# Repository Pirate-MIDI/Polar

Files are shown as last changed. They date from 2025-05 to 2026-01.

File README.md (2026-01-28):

# Polar Pico, Mini, Plus, and Max
This repo contains hardware design files for ESP32-S3 platforms for Greg Smith's firmware which enables MIDI control of the ToneX One from IK Multimedia.
Greg's original project can be found [here](https://github.com/builty/tonexonecontroller)

PIRATE MIDI now manufactures and sells these [Polar controllers](https://www.piratemidi.com/products/polar), and 10% of all sales go to Greg Smith to support his awesome work. Many thanks to Greg for his encouragement and support in making these controllers available.

## Polar Pico
Polar Pico is a screenless MIDI translator for ToneX One and ToneX
- 9V DC Centre Negative 2.1mm Barrel Jack
- 3.5mm TRS (Type A) MIDI Input Jack
- USB Type-C USB Host Jack

Polar Pico powers the ToneX One - no other power needed.
Simply connect your ToneX One or ToneX to the USB port, connect power to the 9V jack, and you can send wired or wireless MIDI.

[Buy a Polar Pico Here](https://piratemidi.com/products/polar?variant=46533908693044)



## Polar Mini
Polar Mini has a 1.69" LCD screen and is a MIDI translator for ToneX One and ToneX
- 9V DC Centre Negative 2.1mm Barrel Jack
- 3.5mm TRS (Type A) MIDI Input Jack
- USB Type-C USB Host Jack

Polar Mini powers the ToneX One - no other power needed.
Simply connect your ToneX One or ToneX to the USB port, connect power to the 9V jack, and you can send wired or wireless MIDI and see your presets and wireless status on the screen.

[Buy a Polar Mini Here](https://piratemidi.com/products/polar?variant=46533908725812)



## Polar Plus
Polar Plus has a 1.69" LCD screen, two built-in footswitches, and is a MIDI translator for ToneX One and ToneX
- 9V DC Centre Negative 2.1mm barrel Jack
- 3.5mm TRS (Type A) MIDI Input Jack
- USB Type-C USB Host Jack
- Two High Quality Momentary Footswitches

Polar Plus powers the ToneX One - no other power needed.
Simply connect your ToneX One or ToneX to the USB port, connect power to the 9V jack, and you can send wired or wireless MIDI and see your presets and wireless status on the screen. The built-in footswitches can be assigned in the web configurator, but scroll through presets by default. 

[Buy a Polar Plus Here](https://piratemidi.com/products/polar?variant=46533908758580)



## Polar Max
Polar Max has a 4.3" Touchscreen LCD, two built-in footswitches, and is a MIDI translator for ToneX One and ToneX with onboard UI for editing presets and parameter. 
- 9V DC Centre Negative 2.1mm Barrel Jack
- 3.5mm TRS (Type A) MIDI Input Jack
- 3.5mm TRS (Type A) MIDI Output Jack (not yet implemented in firmware)
- USB Type-C USB Host Jack
- Two High Quality Momentary Footswitches

Polar Max powers the ToneX One - no other power needed.
Simply connect your ToneX One or ToneX to the USB port, connect power to the 9V jack, and you can send wired or wireless MIDI and see or edit your presets and wireless status on the touchscreen. The built-in footswitches can be assigned in the web configurator, but scroll through presets by default. 

[Buy a Polar Max Here](https://piratemidi.com/products/polar?variant=46900052197428)

Polar Max Context 2 1350px

## New to MIDI?
If MIDI confuses or intimidates you, fear not! We've been helping people get started with MIDI for years, and last year we collated our expertise into two great resources for beginners and power-users alike. **Tones & Technology** is an eBook written specifically to guitarists and pedalboard users to help you understand and get more out of MIDI. The [Foundational Chapter](https://www.tonesandtechnology.com/product/tones-technology-free-chapter) is permanently free to download as a great MIDI primer you can share with your friends, and the [Full eBook](https://www.tonesandtechnology.com/product/tones-tech-pdf) has 135 pages with 75+ custom diagrams and images to help you learn more advanced MIDI control techniques. 

## About Us
PIRATE MIDI is an Australian manufacturer of MIDI controllers, hubs, and more. We love MIDI and we love innovative solutions that help you think less and create more. We ship worldwide from Australia, and we have a workmanship guarantee and a 1 year warranty that we support worldwide.

We've been making MIDI controllers and other devices since 2020. If you'd like to learn more about us, check out our appearance on [The Gear Podcast](https://www.youtube.com/watch?v=aMcJVGF4TDE&t=1s&pp=ygUcdGhlIGdlYXIgcG9kY2FzdCBwaXJhdGUgbWlkaQ%3D%3D) or [Chairmen of the Boards Podcast](https://www.youtube.com/watch?v=8-HLmsmi4O0&t=13s&pp=ygUiY2hhaXJtZW4gb2YgdGhlIGJvYXJkcyBwaXJhdGUgbWlkaQ%3D%3D)

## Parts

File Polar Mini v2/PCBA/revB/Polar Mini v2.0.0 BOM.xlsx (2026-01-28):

Qty | Value | Footprint | Designator | JLC_PREF | PART_NO
2 |  | SOD-323 | D2, D3 | C191023 | SOD323-SCHOTTKY-1A
4 | 100K | 0402-RES | R5, R7, R15, R33 | C25741 | R0402-100K
3 | 100n | 0402_CAP | C8, C12, C14 | C307331 | C0402-100NF-50V-X7R
1 | 10K | 0402-RES | R16 | C25744 | R0402-10K
1 | 10R | 0603-RES | R8 | C22859 | R0603-10R
3 | 10u | 0603_CAP | C5, C7, C1 | C96446 | C0603-10U-25V-X5R
1 | 12V | SOD-323 | D6 | C19077447 | ZENER-SOD-323-12V
1 | 1u | 0402_CAP | C6 | C52923 | C0402-1U-25V-X5R
1 | 220R | 0402-RES | R1 | C25091 | R0402-220R
1 | 22R | 0402-RES | R2 | C25092 | R0402-22R
2 | 22u | 0805_CAP | C4, C11 | C45783 | C0805-22U-25V-X5R
1 | 27K | 0402-RES | R4 | C25771 | R0402-27K
1 | 2K2 | 0402-RES | R9 | C25879 | R0402-2K2
1 | 2u2 | L1008 | L6 | C237482 | L1008-2U2H-2A5
1 | 33R | 0402-RES | R3 | C25105 | R0402-33R
1 | 47u | 1206_CAP | C13 | C96123 | C1206-47U-10V-X5R
4 | 5K1 | 0402-RES | R6, R12, R13, R14 | C25905 | R0402-5K1
1 | DC3.6MM | CUI_PJ-072C-SMT-TR | J1 | C3094066 | PJ-072C-SMT-TR
1 | DISP_LCD_GENERIC_SPI_1.69_WRAPUNDER | TFT_1.69IN_240X280_12P | DISP1 | C9900239771
1 | ESP32-S3-WROOM-1 | XCVR_ESP32-S3-WROOM-1-N16R2 | U3 | C2913205 | ESP32-S3-WROOM-1-N16R2
3 | FIDUCIALROUND_1MM | FIDUCIAL_ROUND_1MM | FD1, FD2, FD3 |  | FIDUCIAL
1 | H11L1S | SMD6 | OK1 | C78589 | H11L1S
2 | LED0603_R | CHIPLED_0603 | D4, D5 | C2286 | LED-0603-RED
2 | MOMENTARYHOR_2.5MM_3MM | SW_B3U-3000P | S3, S4 | C778147
1 | N-channel | SOT23 | Q1 | C8545 | NFET-LOW-SIG-SWITCH-SOT-23-3
2 | SCREW-FASTENER2.5 | M2.5-PANHEAD-VIA | MP1, MP2
1 | SI2309CDS | SOT23 | Q6 | C10493 | SI2309
14 | TEST_PADSB1,27 | B1,27 | TP1, TP2, TP3, TP4, TP5, TP7, TP8, TP9, TP10, TP11, TP12, TP13, TP14, TP15
1 | TLV76733DRV | SON65P200X200X80-7N | U5 | C2848334 | TLV76733DRVR
1 | TPS629206DRLR | SOT-583 | U8 | C5219292 | TPS629206DRLR
2 | TRS-TIP-RING-SW | PJ-342B | J2, J3 | C7507452 | PJ-342 141
1 | USBC_2.0 | 12402012E212A | J4 | C2988369 | USBC-2.0-TOP

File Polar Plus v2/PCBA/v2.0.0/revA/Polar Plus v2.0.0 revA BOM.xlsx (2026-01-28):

Qty | Value | Footprint | Designator | JLC_PREF | PART_NO
1 |  | DO-214AC | D3 | C151924
1 |  | SOD-123 | D5 | C82544
1 |  | SOD-323 | D1 | C191023 | SOD323-SCHOTTKY-1A
6 | 100K | 0402-RES | R7, R13, R15, R27, R33, R49 | C25741 | R0402-100K
10 | 100n | 0402_CAP | C4, C6, C7, C9, C13, C14, C16, C26, C29, C60 | C307331 | C0402-100NF-50V-X7R
1 | 10K | 0402-RES | R50 | C25744 | R0402-10K
1 | 10R | 0603-RES | R8 | C22859 | R0603-10R
3 | 10u | 0603_CAP | C5, C12, C15 | C96446 | C0603-10U-25V-X5R
1 | 12V | SOD-323 | D6 | C19077447 | ZENER-SOD-323-12V
4 | 1K | 0402-RES | R5, R21 | C11702 | R0402-1K
2 | 1u | 0402_CAP | C1, C2 | C52923 | C0402-1U-25V-X5R
1 | 200K | 0402-RES | R6 | C25764 | R0402-200K
2 | 220R | 0402-RES | R1, R16, R9, R19 | C25091 | R0402-220R
3 | 22K | 0402-RES | R11, R14, R23 | C25768 | R0402-22K
1 | 22R | 0402-RES | R2 | C25092 | R0402-22R
1 | 22u | 0603_CAP | C10 | C59461 | C0603-22UF-6V3-X5R
1 | 22u | 0805_CAP | C3 | C45783 | C0805-22U-25V-X5R
1 | 27K | 0402-RES | R10 | C25771 | R0402-27K
2 | 2K2 | 0402-RES | R43, R44 | C25879 | R0402-2K2
2 | 2u2 | L1008 | L1, L2 | C237482 | L1008-2U2H-2A5
2 | 33K | 0402-RES | R12, R24 | C25779 | R0402-33K
1 | 33R | 0402-RES | R3 | C25105 | R0402-33R
4 | 47u | 1206_CAP | C8, C11, C27, C28 | C96123 | C1206-47U-10V-X5R
5 | 5K1 | 0402-RES | R4, R17, R29, R31, R32 | C25905 | R0402-5K1
1 | 741G32 | SOT23-5 | U5 | C7470
2 | ARGBSK6812-MINI-E | SK6812MINI-E | LED1, LED2 | C5149201 | SK6812MINI-E
2 | COMP_SINGLE_5PIN | SOT23-5 | U1, U3 | C5310980
1 | DCPCB_MOUNT_TH_SLOT | DCJACK_2MM_PTH_SLOT | J4 |  | DC-2.1-TH-SLOT
1 | DISP_LCD_GENERIC_SPI_1.69_WRAPUNDER | TFT_1.69IN_240X280_12P | DISP1 | C9900239771
1 | ESP32-S3-WROOM-1 | XCVR_ESP32-S3-WROOM-1-N16R2 | U8 | C2913205 | ESP32-S3-WROOM-1-N16R2
3 | FIDUCIALROUND_1MM | FIDUCIAL_ROUND_1MM | FD1, FD2, FD3 |  | FIDUCIAL
1 | H11L1S | SMD6 | OK1 | C78589 | H11L1S
2 | LED0603_R | CHIPLED_0603 | D9, D10 | C2286 | LED-0603-RED
2 | LEDIR12-21C/TR8 | IR12-21C/TR8 | D2, D4 | C181893 | IR26-61C/L302/TR8
2 | MOMENTARYHOR_2.5MM_3MM | SW_B3U-3000P | S1, S2 | C778147
1 | N-channel | SOT23 | Q1 | C8545 | NFET-LOW-SIG-SWITCH-SOT-23-3
2 | N_PHOTO | PT12-21B-TR8 | Q2, Q4 | C264383
2 | SCREW-FASTENER3 | M3-PANHEAD-VIA | MP1, MP2
1 | SI2309CDS | SOT23 | Q6 | C10493 | SI2309
2 | TEST_PADSB1,27 | B1,27 | TP14, TP15
2 | TPS56124 | SOT-563 | U2, U4 | C42040978 | TPS561243DRLR
2 | TRS-TIP-RING-SW | PJ-342B | J5, J6 | C7507452 | PJ-342 141
1 | USBC_2.0 | 12402012E212A | J3 | C2988369 | USBC-2.0-TOP

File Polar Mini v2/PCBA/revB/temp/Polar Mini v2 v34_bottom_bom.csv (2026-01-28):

Comment | Designator | Footprint | LCSC Part #
1u | D2 D3 C6 | 0402_CAP
2K2 | R9 | 0402-RES
2u2 | L6 | L1008
5K1 | R6 R12 R13 R14 | 0402-RES
10K | R16 | 0402-RES
10R | R8 | 0603-RES
10V | D6 | SOD-323
10u | C1 C5 C7 | 0603_CAP
22R | R2 | 0402-RES
22u | C4 C11 | 0805_CAP
27K | R4 | 0402-RES
33R | R3 | 0402-RES
47u | C13 | 1206_CAP
100K | R5 R7 R15 R33 | 0402-RES
100n | C8 C12 C14 | 0402_CAP
220R | R1 | 0402-RES
DC3.6MM | J1 | CUI_PJ-072C-SMT-TR
ESP32-S3-WROOM-1 | U3 | XCVR_ESP32-S3-WROOM-1-N16R2
FIDUCIALROUND_1MM | FD1 FD2 FD3 | FIDUCIAL_ROUND_1MM
H11L1S | OK1 | SMD6
LED0603_R | D4 D5 | CHIPLED_0603
MOMENTARYHOR_2.5MM_3MM | S3 S4 | SW_B3U-3000P
N-channel | Q1 | SOT23
SI2309CDS | Q6 | SOT23
TEST_PADSB1 27 | TP1 | B1 27
TEST_PADSB1 27 | TP2 | B1 27
TEST_PADSB1 27 | TP3 | B1 27
TEST_PADSB1 27 | TP4 | B1 27
TEST_PADSB1 27 | TP5 | B1 27
TEST_PADSB1 27 | TP7 | B1 27
TEST_PADSB1 27 | TP8 | B1 27
TEST_PADSB1 27 | TP9 | B1 27
TEST_PADSB1 27 | TP10 | B1 27
TEST_PADSB1 27 | TP11 | B1 27
TEST_PADSB1 27 | TP12 | B1 27
TEST_PADSB1 27 | TP13 | B1 27
TEST_PADSB1 27 | TP14 | B1 27
TEST_PADSB1 27 | TP15 | B1 27
TLV76733DRV | U5 | SON65P200X200X80-7N
TPS629206DRLR | U8 | SOT-583
TRS-TIP-RING-SW | J2 J3 | PJ-342B
USBC_2.0 | J4 | 12402012E212A

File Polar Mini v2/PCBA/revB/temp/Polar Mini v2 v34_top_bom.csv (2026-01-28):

Comment | Designator | Footprint | LCSC Part #
DISP_LCD_GENERIC_SPI_1.69_WRAPUNDER | DISP1 | TFT_1.69IN_240X280_12P

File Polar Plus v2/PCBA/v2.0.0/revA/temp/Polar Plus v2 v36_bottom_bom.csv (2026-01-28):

Comment | Designator | Footprint | LCSC Part #
1K | D1 D3 D5 R5 R9 R19 R21 | 0402-RES
1u | C1 C2 | 0402_CAP
2K2 | R43 R44 | 0402-RES
2u2 | L1 L2 | L1008
5K1 | R4 R17 R29 R31 R32 | 0402-RES
10K | R50 | 0402-RES
10R | R8 | 0603-RES
10u | C5 C12 C15 | 0603_CAP
12V | D6 | SOD-323
22K | R11 R14 R23 | 0402-RES
22R | R2 | 0402-RES
22u | C3 | 0805_CAP
22u | C10 | 0603_CAP
27K | R10 | 0402-RES
33K | R12 R24 | 0402-RES
33R | R3 | 0402-RES
47u | C8 C11 C27 C28 | 1206_CAP
100K | R7 R13 R15 R27 R33 R49 | 0402-RES
100n | C4 C6 C7 C9 C13 C14 C16 C26 C29 C60 | 0402_CAP
200K | R6 | 0402-RES
220R | R1 R16 | 0402-RES
741G32 | U5 | SOT23-5
ARGBSK6812-MINI-E | LED1 LED2 | SK6812MINI-E
COMP_SINGLE_5PIN | U1 U3 | SOT23-5
ESP32-S3-WROOM-1 | U8 | XCVR_ESP32-S3-WROOM-1-N16R2
FIDUCIALROUND_1MM | FD1 FD2 FD3 | FIDUCIAL_ROUND_1MM
H11L1S | OK1 | SMD6
LED0603_R | D9 D10 | CHIPLED_0603
LEDIR12-21C/TR8 | D2 D4 | IR12-21C/TR8
MOMENTARYHOR_2.5MM_3MM | S1 S2 | SW_B3U-3000P
N-channel | Q1 | SOT23
N_PHOTO | Q2 Q4 | PT12-21B-TR8
SI2309CDS | Q6 | SOT23
TEST_PADSB1 27 | TP14 | B1 27
TEST_PADSB1 27 | TP15 | B1 27
TPS56124 | U2 U4 | SOT-563
TRS-TIP-RING-SW | J5 J6 | PJ-342B
USBC_2.0 | J3 | 12402012E212A

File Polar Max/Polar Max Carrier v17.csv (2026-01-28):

Comment | Designator | Footprint | JLCPCB Part # | Quantity | MPN
1 | D7 | SOD-323 |  | 1 | 1N4148WX-TP | 1N4148
2 | J7 | 1X3_PADS |  | 1 |  | 1X3PADS
3 | IC1 | SO14 |  | 1 | 74HC14-SOIC-14 | 7414D
4 | D8, D9, D10 | DO-214AC |  | 3 |  | BIDIRECTIONAL
5 | J1 | DCJACK_2MM_PTH_SLOT |  | 1 | DC-2.1-TH-SLOT | DCPCB_MOUNT_TH_SLOT
6 | D4 | SOD-323 |  | 1 | SOD323-SCHOTTKY-1A | DIODE-SCHOTTKYGEN_SOD-323
7 | D1 | SOD-323 |  | 1 | ZENER-SOD-323-12V | DIODE-ZENER12V
8 | FD1, FD2, FD3 | FIDUCIAL_ROUND_1MM |  | 3 | FIDUCIAL | FIDUCIALROUND_1MM
9 | F1, F2 | 0603-FUSE |  | 2 | PTC-0603-6V-1.5A | FUSE1PPTC_0603_6V_1.5A
10 | OK1 | SMD6 |  | 1 | H11L1S | H11L1S
11 | J3, J4 | JST_S2B-PH-SM4-TB |  | 2 | S2B-PH-SM4-TB(LF)(SN) | JST_PH_2
12 | J2 | JST_SM12B-SRSS-TB |  | 1 |  | JST_SH_12
13 | D3 | CHIPLED_0603 |  | 1 | LED-0603-GREEN | LED0603_G
14 | D2, D5, D6 | CHIPLED_0603 |  | 3 | LED-0603-RED | LED0603_R
15 | U2 | SO08 |  | 1 |  | RS485SOIC
16 | MP1, MP2, MP3, MP4 | M3-PANHEAD-VIA |  | 4 |  | SCREW-FASTENER3
17 | Q1 | SOT23 |  | 1 | SI2309 | SI2309CDS
18 | C3, C4, C5, C6, C7 | 0603_CAP |  | 5 | C0603-100NF-50V-X7R | SMD-MLCCC0603-100N-50V-X7R
19 | C1 | 0805_CAP |  | 1 | C0805-10UF-25V-X7R | SMD-MLCCC0805-10U-25V-X7R
20 | R4, R11 | 0603-RES |  | 2 | R0603-1K | STDR0603-1K
21 | R9 | 0603-RES |  | 1 | R0603-20R | STDR0603-20R
22 | R5, R6, R7 | 0603-RES |  | 3 | R0603-220R | STDR0603-220R
23 | R1 | 0603-RES |  | 1 | R0603-2K2 | STDR0603-2K2
24 | R8 | 0603-RES |  | 1 | R0603-33R | STDR0603-33R
25 | R2 | 0603-RES |  | 1 | R0603-39K | STDR0603-39K
26 | R13 | 0603-RES |  | 1 | RC0603FR-0756KL | STDR0603-56K
27 | R3, R10, R14, R15, R16 | 0603-RES |  | 5 | R0603-5K1 | STDR0603-5K1
28 | J5, J6 | CUI_SJ1-3525N |  | 2 | SJ1-3525N | TRS

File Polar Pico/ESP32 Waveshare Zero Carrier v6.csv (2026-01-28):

Comment | Designator | Footprint | JLCPCB Part # | Quantity | MPN
1 | L1 | L1008 |  | 1 | L1008-2U2H-2A5 | 2-PIN-INDUCTORL1008-2U2-2A5
2 | J2 | DCJACK_2MM_PTH_SLOT |  | 1 | DC-2.1-TH-SLOT | DCPCB_MOUNT_TH_SLOT
3 | D1, D2 | SOD-323 |  | 2 | SOD323-SCHOTTKY-1A | DIODE-SCHOTTKYGEN_SOD-323
4 | FD1, FD2, FD3 | FIDUCIAL_ROUND_1MM |  | 3 | FIDUCIAL | FIDUCIALROUND_1MM
5 | OK1 | SMD6 |  | 1 | H11L1S | H11L1S
6 | D3 | CHIPLED_0603 |  | 1 | LED-0603-GREEN | LED0603_G
7 | MP1, MP2, MP3, MP4 | M3-PANHEAD-VIA |  | 4 |  | SCREW-FASTENER3
8 | C1 | 0805_CAP |  | 1 | C0805-10UF-25V-X7R | SMD-MLCCC0805-10U-25V-X7R
9 | C2 | 1210_CAP |  | 1 | C1210-22U-25V | SMD-MLCCC1210-22U-25V-X7R
10 | R4 | 0603-RES |  | 1 | R0603-100K | STDR0603-100K
11 | R5 | 0603-RES |  | 1 | R0603-1K | STDR0603-1K
12 | R1 | 0603-RES |  | 1 | R0603-220R | STDR0603-220R
13 | R3 | 0603-RES |  | 1 | R0603-27K | STDR0603-27K
14 | R2 | 0603-RES |  | 1 | R0603-5K1 | STDR0603-5K1
15 | U1 | SOT-5X3 |  | 1 | TPS629206DRLR | TPS629206DRLR
16 | J1 | CUI_SJ1-3525N |  | 1 | SJ1-3525N | TRS
17 | U2 | WAVESHARE_ESP32_ZERO |  | 1 |  | WAVESHARE_ESP32_ZERO

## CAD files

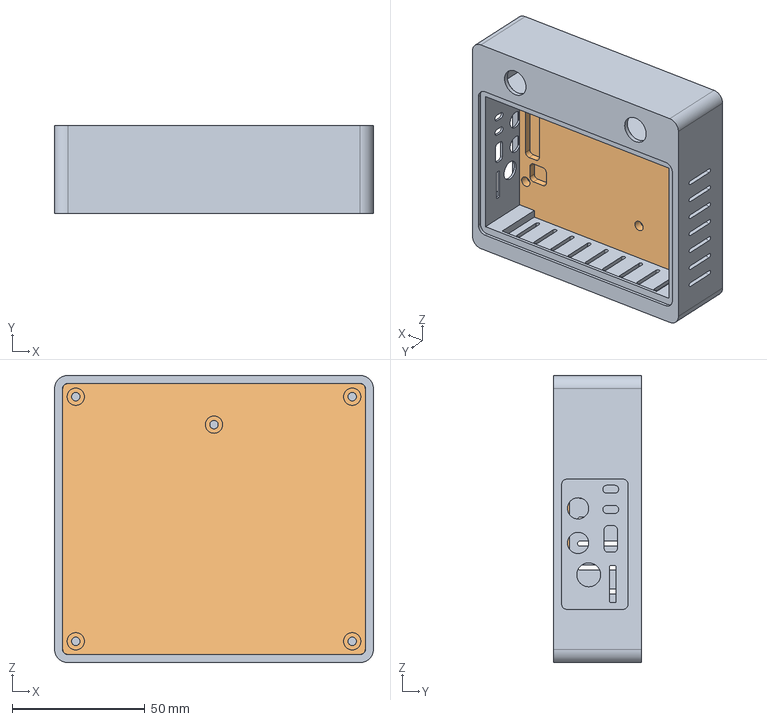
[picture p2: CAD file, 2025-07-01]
Polar Max/Polar Max Enclosure v105.step
120.0 x 33.0 x 108.0 mm
Top
Middle

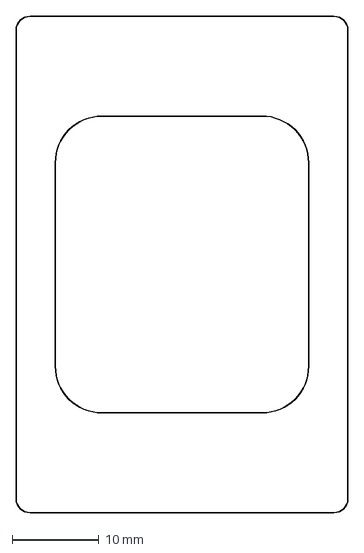
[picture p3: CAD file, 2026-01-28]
Polar Mini v2/Enclosure/Polar Mini v2 Overlay Sketch.dxf
38.2 x 57.2 mm

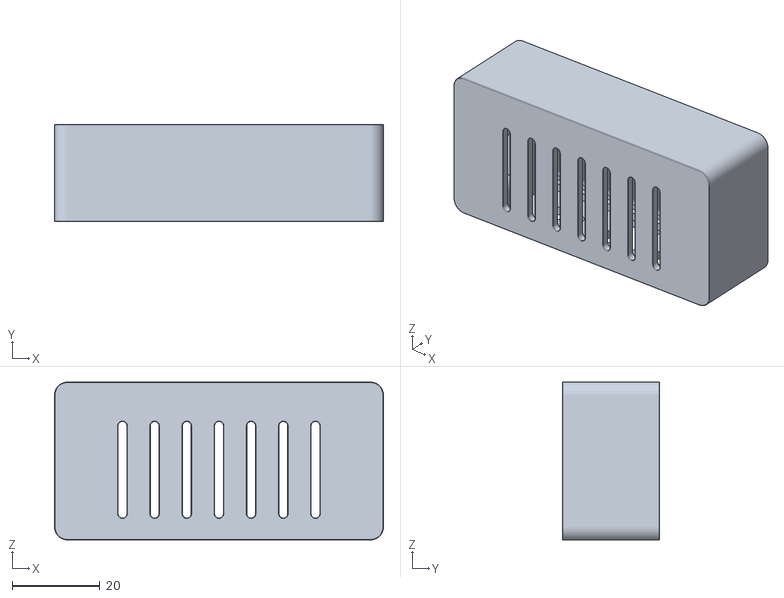
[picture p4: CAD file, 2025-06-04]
Polar Pico/Polar Pico Enclosure v43.stl
75.0 x 22.2 x 36.0

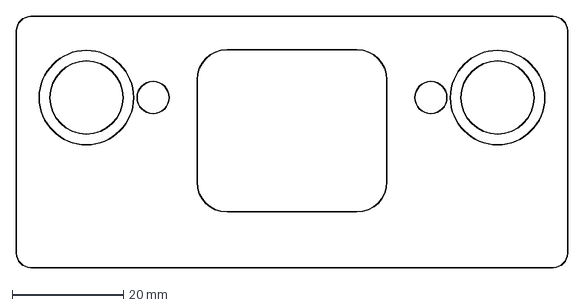
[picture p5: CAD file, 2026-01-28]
Polar Plus v2/Enclosure/Polar Plus v2 Overlay Sketch.dxf
99.2 x 45.2 mm

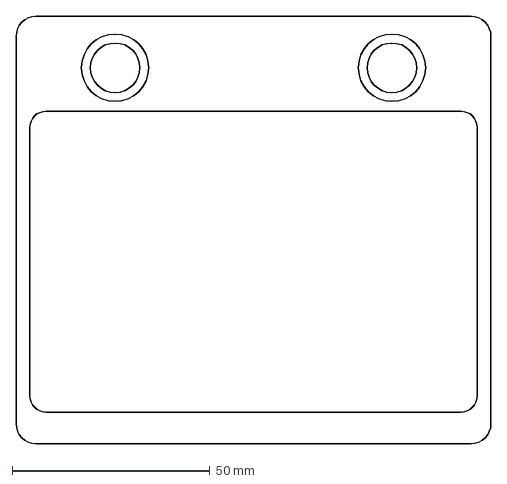
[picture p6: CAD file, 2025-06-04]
Polar Max/Polar Max Overlay.dxf
120.0 x 108.0 mm

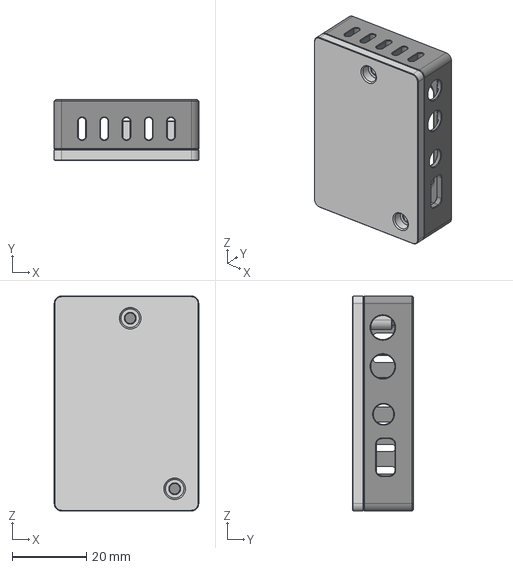
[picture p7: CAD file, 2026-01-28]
Polar Mini v2/Enclosure/Polar Mini v2 Enclosure v35.step
39.0 x 16.5 x 58.0 mm
Bottom
Top

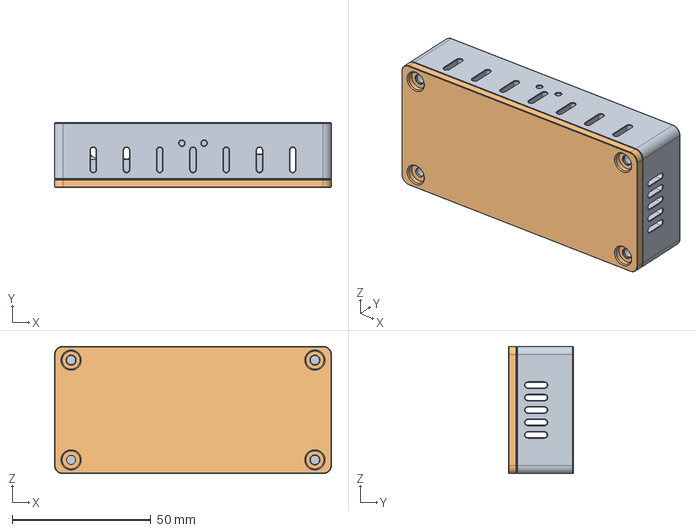
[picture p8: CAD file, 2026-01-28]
Polar Plus v2/Enclosure/Polar Plus v2 Enclosure v44.step
100.0 x 23.5 x 46.0 mm
Top
Bottom

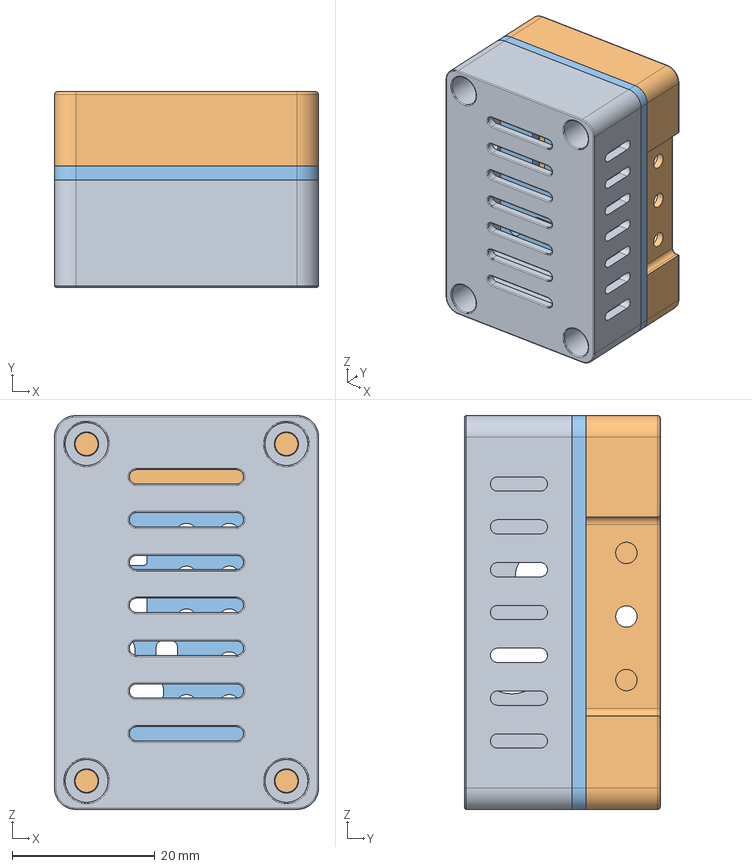
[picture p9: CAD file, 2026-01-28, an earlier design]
Polar Mini/Polar Mini Enclosure v84.step
37.0 x 27.4 x 55.2 mm
Bottom
Top
Middle

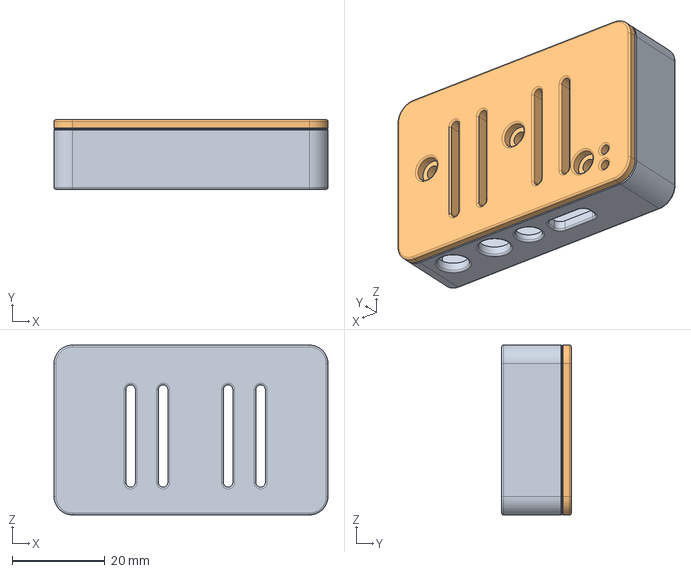
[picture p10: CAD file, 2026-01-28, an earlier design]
Polar Pico v2/Enclosure/Polar Pico Enclosure v40.step
59.0 x 15.0 x 36.6 mm

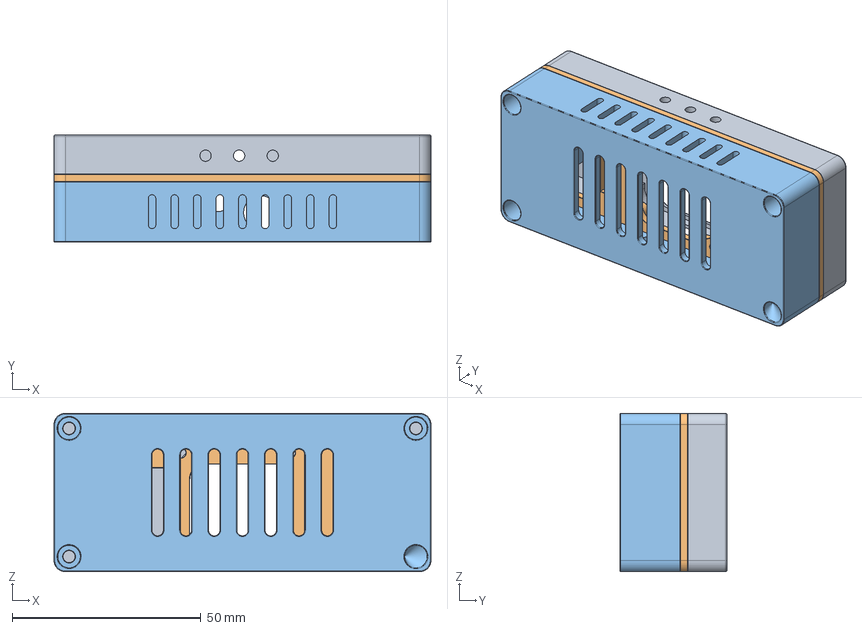
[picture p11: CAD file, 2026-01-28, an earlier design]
Polar Plus/Polar Plus Enclosure v49.step
100.0 x 28.4 x 42.0 mm
Top
Middle
Bottom

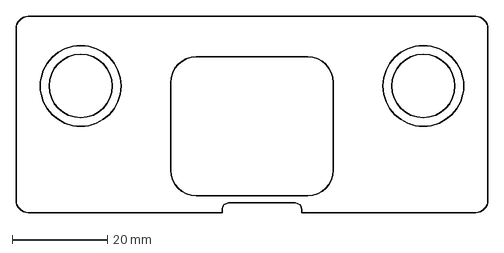
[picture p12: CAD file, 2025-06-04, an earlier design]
Polar Plus/Polar Plus Overlay.dxf
99.2 x 41.2 mm

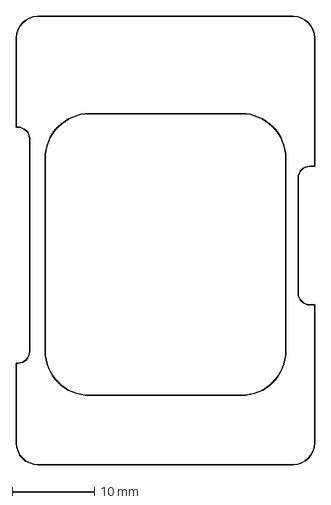
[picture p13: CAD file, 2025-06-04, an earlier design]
Polar Mini/Polar Mini Overlay DXF.dxf
36.2 x 54.4 mm

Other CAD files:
Polar Mini v2/Enclosure/Polar Mini v2 Enclosure v37.step
Polar Mini v2/Enclosure/Polar Mini v2 Enclosure v38.step
Polar Mini/Polar Mini Enclosure v85.stl
Polar Plus/Polar Plus Enclosure v49.stl

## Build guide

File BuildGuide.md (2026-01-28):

# Polar Controller DIY Build Guide

> ⚠️ This guide is for DIY builders and tinkerers. Pirate MIDI sells fully assembled units, but as part of our open-source commitment, we’re making this construction guide available for personal and non-commercial builds.

**[1. Hardware Assembly](https://github.com/Builty/TonexOneController/blob/main/WebConfiguration.md#entering-web-control)**

**[2. Installing Firmware](https://github.com/Builty/TonexOneController/blob/main/WebConfiguration.md#entering-web-control)**

**[3. Testing & Power-Up](https://github.com/Builty/TonexOneController/blob/main/WebConfiguration.md#entering-web-control)**

---

## 🧰 What You'll Need

Each variant of the Polar controller shares common elements. Below are general tools and materials you'll need.

### 🛠 Tools

- Soldering iron + solder
- Screwdriver set
- Heat-set insert tool or soldering iron with insert tip
- Flush cutters (for preparing wires)
- 3D printer (for enclosure) or printed parts
- Acrylic glue or double-sided tape (for protective overlay)
- JST crimping tool (if not using pre-crimped JST leads)

---

## 🔗 Polar Resources

- 📐 3D Enclosure Models: [Polar Pico](https://github.com/Pirate-MIDI/Polar/tree/main/Polar%20Pico), [Polar Mini](https://github.com/Pirate-MIDI/Polar/tree/main/Polar%20Mini), [Polar Plus](https://github.com/Pirate-MIDI/Polar/tree/main/Polar%20Plus), [Polar Max](https://github.com/Pirate-MIDI/Polar/tree/main/Polar%20Max)
- ⚡ Schematic & PCB Layout: [Polar Pico](https://github.com/Pirate-MIDI/Polar/tree/main/Polar%20Pico), [Polar Mini](https://github.com/Pirate-MIDI/Polar/tree/main/Polar%20Mini), [Polar Plus](https://github.com/Pirate-MIDI/Polar/tree/main/Polar%20Plus), [Polar Max](https://github.com/Pirate-MIDI/Polar/tree/main/Polar%20Max)
- 📄 [Firmware Source Code](https://github.com/Builty/TonexOneController)
- 📦 [Buy Pre-Assembled Units](https://piratemidi.com/)
- 📦 [Buy Waveshare ESP32 Boards](https://waveshare.com)

---

## 🔩 General Components List For All Variants

| Component | Description |
|---|--- |
| Custom PCB | Input & power designed for each variant |
| Waveshare Board | ESP32-S3 Variants (main brain) |
| 3D Printed Enclosure | STL provided; print in PLA or PETG (preferred)  |
| Heat-Set Inserts | Brass M3 |
| M3 & M2 Screws | Machine Thread (not tapping) |
| JST Connector | For PCB to Waveshare connection |
| Acrylic Overlay (optional)| Laser-cut, protective top panel |

---

# 🔧 Hardware Assembly Instructions

Each variant has its own steps below. If you're unsure which variant you're building, check the product comparison table on [our website](https://piratemidi.com/products/polar).

---

## Polar Pico (No Screen)

Minimalist version – ideal for under-board use.

**[📺 Polar Pico Assembly Video Guide COMING SOON!]()**

### Parts List

- 1x Polar Pico PCB
- [1x Waveshare ESP32-S3 Zero](https://www.waveshare.com/esp32-s3-zero.htm)
- 1x 3D printed enclosure 
- [4x M3x4mmx5mm Heat-set Inserts](https://github.com/user-attachments/assets/3e2e96b9-6922-4ddc-a0e5-bb1fc9a778b4)
- 4x M3x7mm screws
- [1x JST-SH 12-pin Dual-Male Cable](https://github.com/user-attachments/assets/c0d687e7-e608-4e23-b043-ad0c6be05575)
- Optional: Acrylic Protective Overlay

### Steps

1. **Solder Waveshare headers to PCB**
   Step 1: Soldering headers

2. **Heat-insert brass M3 inserts into 3D printed enclosure**
   Step 3: Heat set inserts

3. **Mount PCB and Waveshare into enclosure and secure with screws**

4. *(Optional)* Apply acrylic overlay using adhesive or standoffs.

---

## Polar Mini (Screen, No Switches)

Screen-only version for visual feedback in tight spaces.

**[📺 Polar Mini Assembly Video Guide COMING SOON!]()**

### Parts List

- 1x Polar Mini PCB  
- [1x Waveshare ESP32-S3 1.69](https://www.waveshare.com/esp32-s3-lcd-1.69.htm)
- 1x 3D printed enclosure
- [4x M3x4mmx5mm Heat-set Inserts](https://github.com/user-attachments/assets/3e2e96b9-6922-4ddc-a0e5-bb1fc9a778b4)
- 4x M3x7mm screws
- [1x JST-SH 12-pin Dual-Male Cable](https://github.com/user-attachments/assets/c0d687e7-e608-4e23-b043-ad0c6be05575)
- Optional: Acrylic Protective Overlay

### Steps

(Same general steps as Pico, with attention to screen alignment)

1. **Connect PCB to Waveshare 1.69 module with JST cable**
   Step: Screen and MCU soldering

2. **Heat-insert brass M3 inserts into 3D printed enclosure**

3. **Mount PCB and Screen into enclosures with care to align screen**

4. **Close enlclosure with screws**

5.  *(Optional)* Apply acrylic overlay using adhesive or standoffs.

---

## Polar Plus (Screen + 2 Footswitches)

**[📺 Polar Plus Assembly Video Guide COMING SOON!]()**

This version includes two footswitches for changing presets or other toggles.

### Additional Parts

- 2x Momentary, Normally Open (NO) footswitches   
- Wiring for switches

### Steps

1. **Solder wires to footswitches**
2. **Insert footswitches in enclosure and fasten**
3. **Solder footswitch wires onto PCB**
4. **Attach screen and MCU as per Mini**
5. **Secure all components into enclosure**
   Footswitch mounting
6. *(Optional)* Apply acrylic overlay

---

## Polar Max (Touchscreen + Full Control)

The flagship controller with touchscreen and full ToneX One editing onboard.

**[📺 Polar Max Assembly Video Guide](https://youtu.be/EYmiK8_B6EI)**

### Additional Parts

- [1x Waveshare 4.3b Touchscreen Module](https://www.waveshare.com/esp32-s3-touch-lcd-4.3b.htm) 
- 2x Momenatry Normally-Open (NO) Footswitches
- 1x JST-SH 12-pin connector with ferrules or open wires on other end

### Steps

1. **Install heat-set inserts**
2. **Solder wires to footswitches**
3. **Install footswitches into enclosure**
4. **Secure display into 3D printed housing**
5. **Fasten PCB to bottom plate of enclosure**
6. **Connect PCB and Waveshare with JST to Ferrules wire harness - See circuit diagram for details**
7. **Connect footswitches to PCB**
8. **Close enclosure and fasten with screws**
9. *(Optional)* Install overlay or protective cover

---

# 🖥️ Installing Firmware

To install the firmware, follow the instructions [found on the original project page here](https://github.com/Builty/TonexOneController/blob/main/FirmwareUploading.md).

---

# 🧪 Testing & Power-Up

1. Power via USB or 9V 2.1mm center-negative barrel jack  
2. Connect to [Web Configurator](https://github.com/Builty/TonexOneController/blob/main/WebConfiguration.md#entering-web-control) 
3. Test MIDI input and screen functionality.
   
   > ⚠️ Wired MIDI needs to be activated in the web configurator
4. Confirm footswitch response. (if applicable)

---

## 🧼 Tips & Troubleshooting

- If the 9v Power or MIDI input doesn't work, double-check the JST pinout or your manual wiring if you didn't use JST.
- Waveshare boards may not have factory firmware. Flash firmware before deciding your unit is "dead".
- Over-tightening screws can crack the enclosure. Don’t overdo it.
- If you have a construction issue, you can contact us in our [Discord Server](https://discord.gg/x722K7ksA6) (Polar Channel), or on the original open source project discussion tab. 

---

## 📸 Contributing

Found an error in these instructions? Feel free to submit a pull request!

---

## 📜 License

This project is licensed under the MIT License. Commercial resale of DIY units is not permitted under our license.

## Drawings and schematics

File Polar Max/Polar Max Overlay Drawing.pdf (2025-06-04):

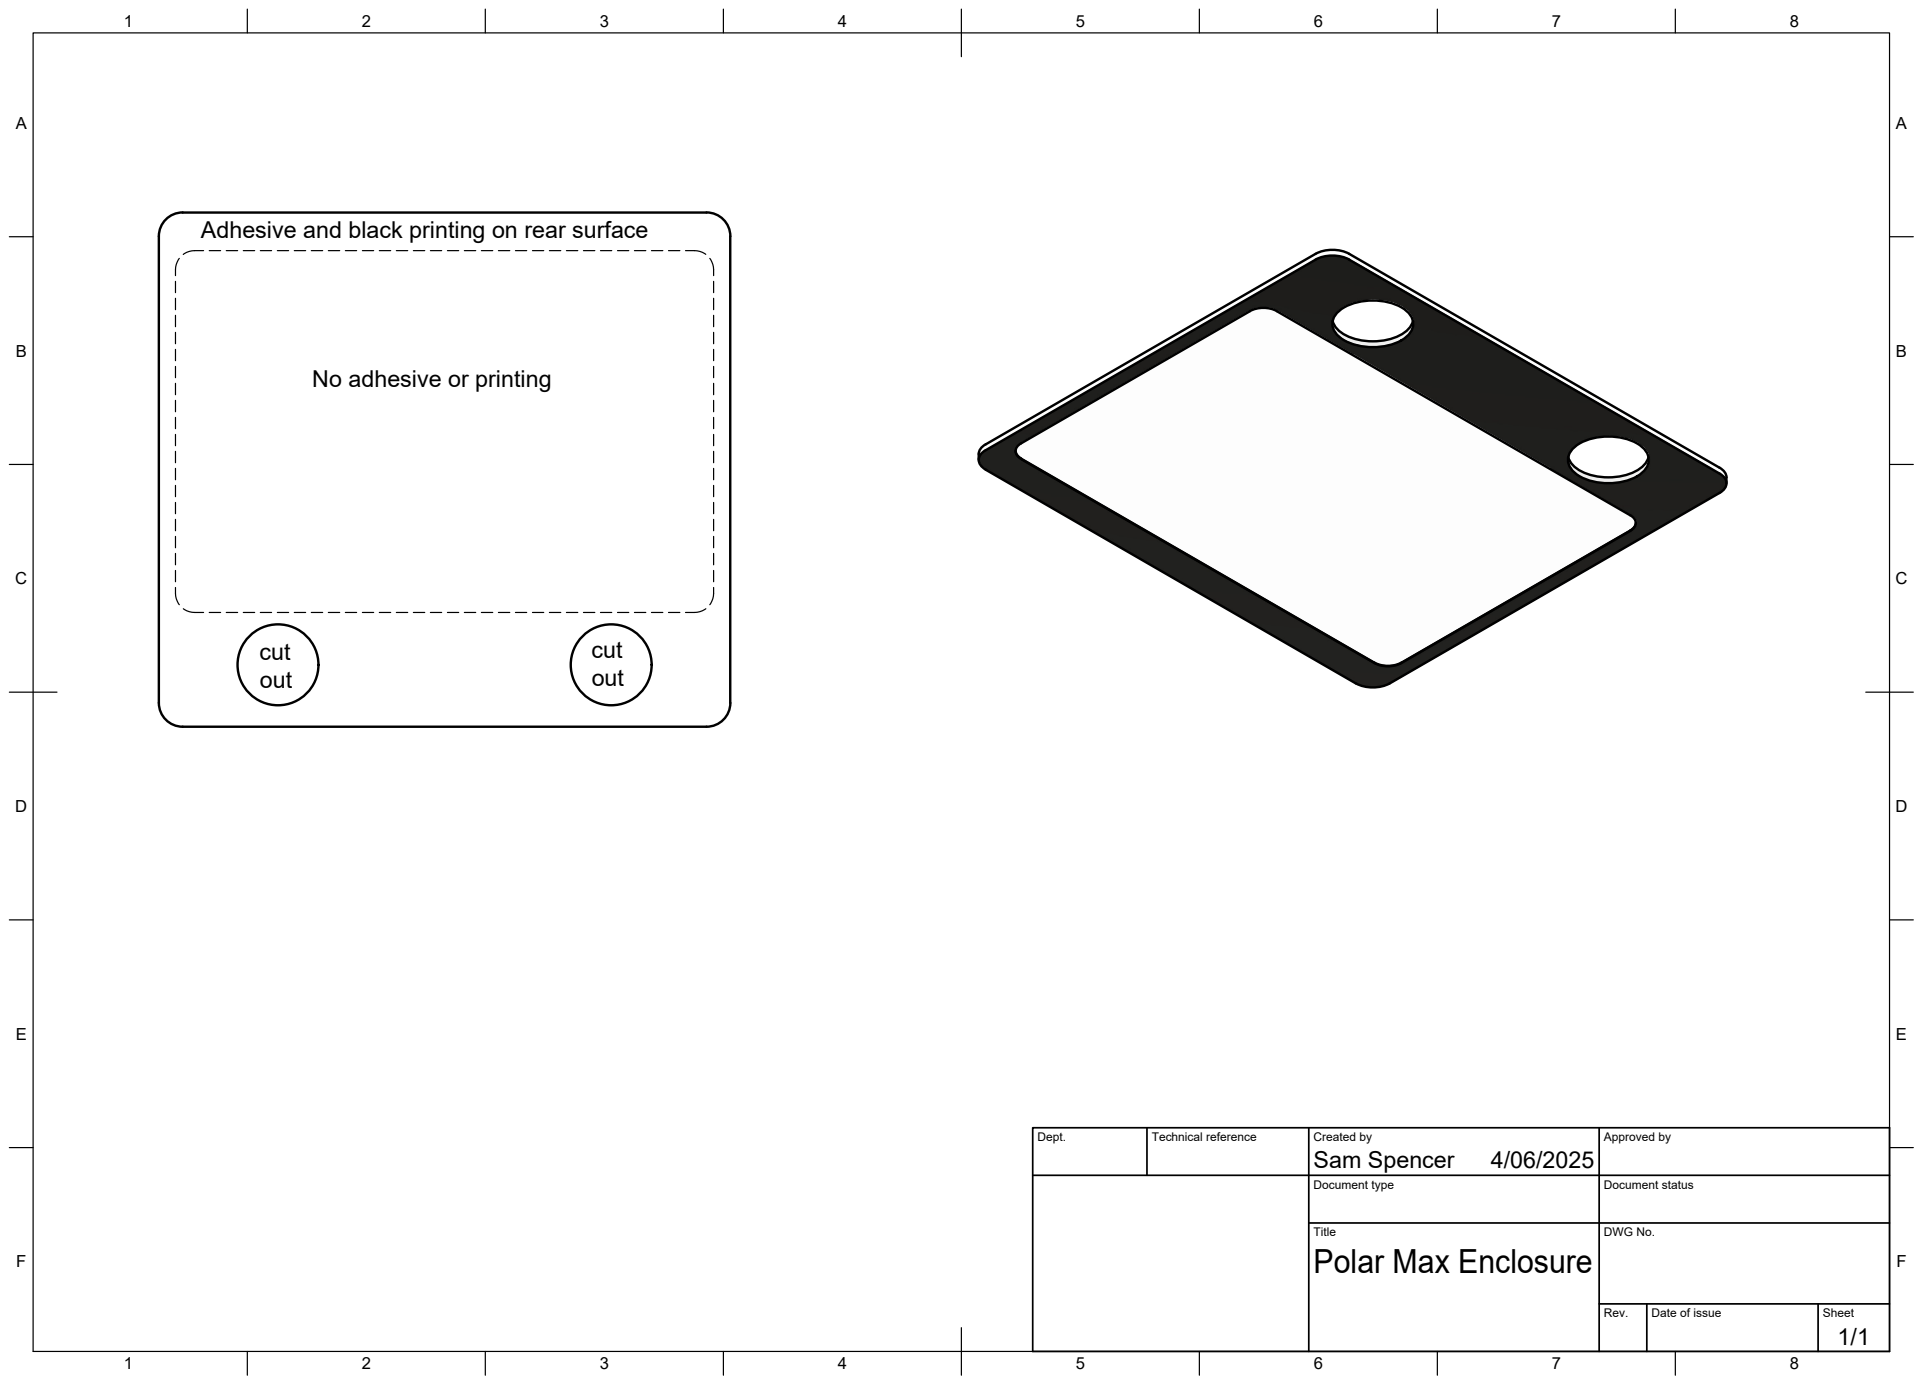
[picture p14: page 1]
Title; DWG No.; Rev.; Date of issue; Sheet

Adhesive and black printing on rear surface

No adhesive or printing

Dept. | Technical reference | Created by Sam Spencer 4/06/2025 | Approved by

Document type | Document status

Polar Max Enclosure

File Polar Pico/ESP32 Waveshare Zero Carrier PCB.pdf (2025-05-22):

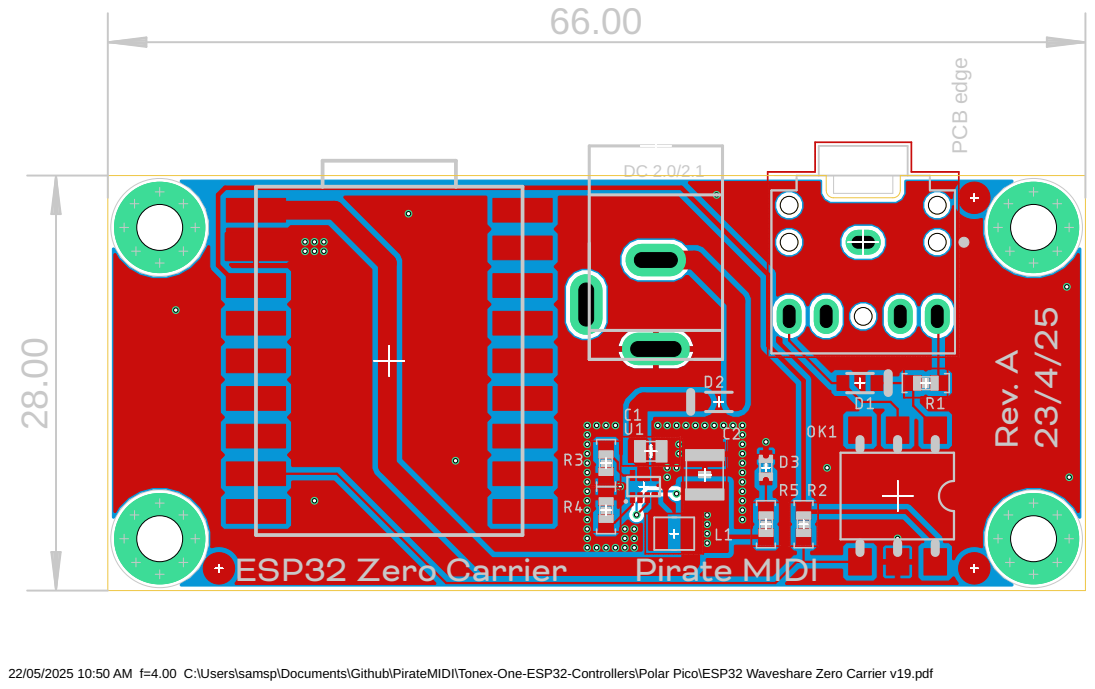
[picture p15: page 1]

22/05/2025 10:50 AM f=4.00 C:\Users\samsp\Documents\Github\PirateMIDI\Tonex-One-ESP32-Controllers\Polar Pico\ESP32 Waveshare Zero Carrier v19.pdf

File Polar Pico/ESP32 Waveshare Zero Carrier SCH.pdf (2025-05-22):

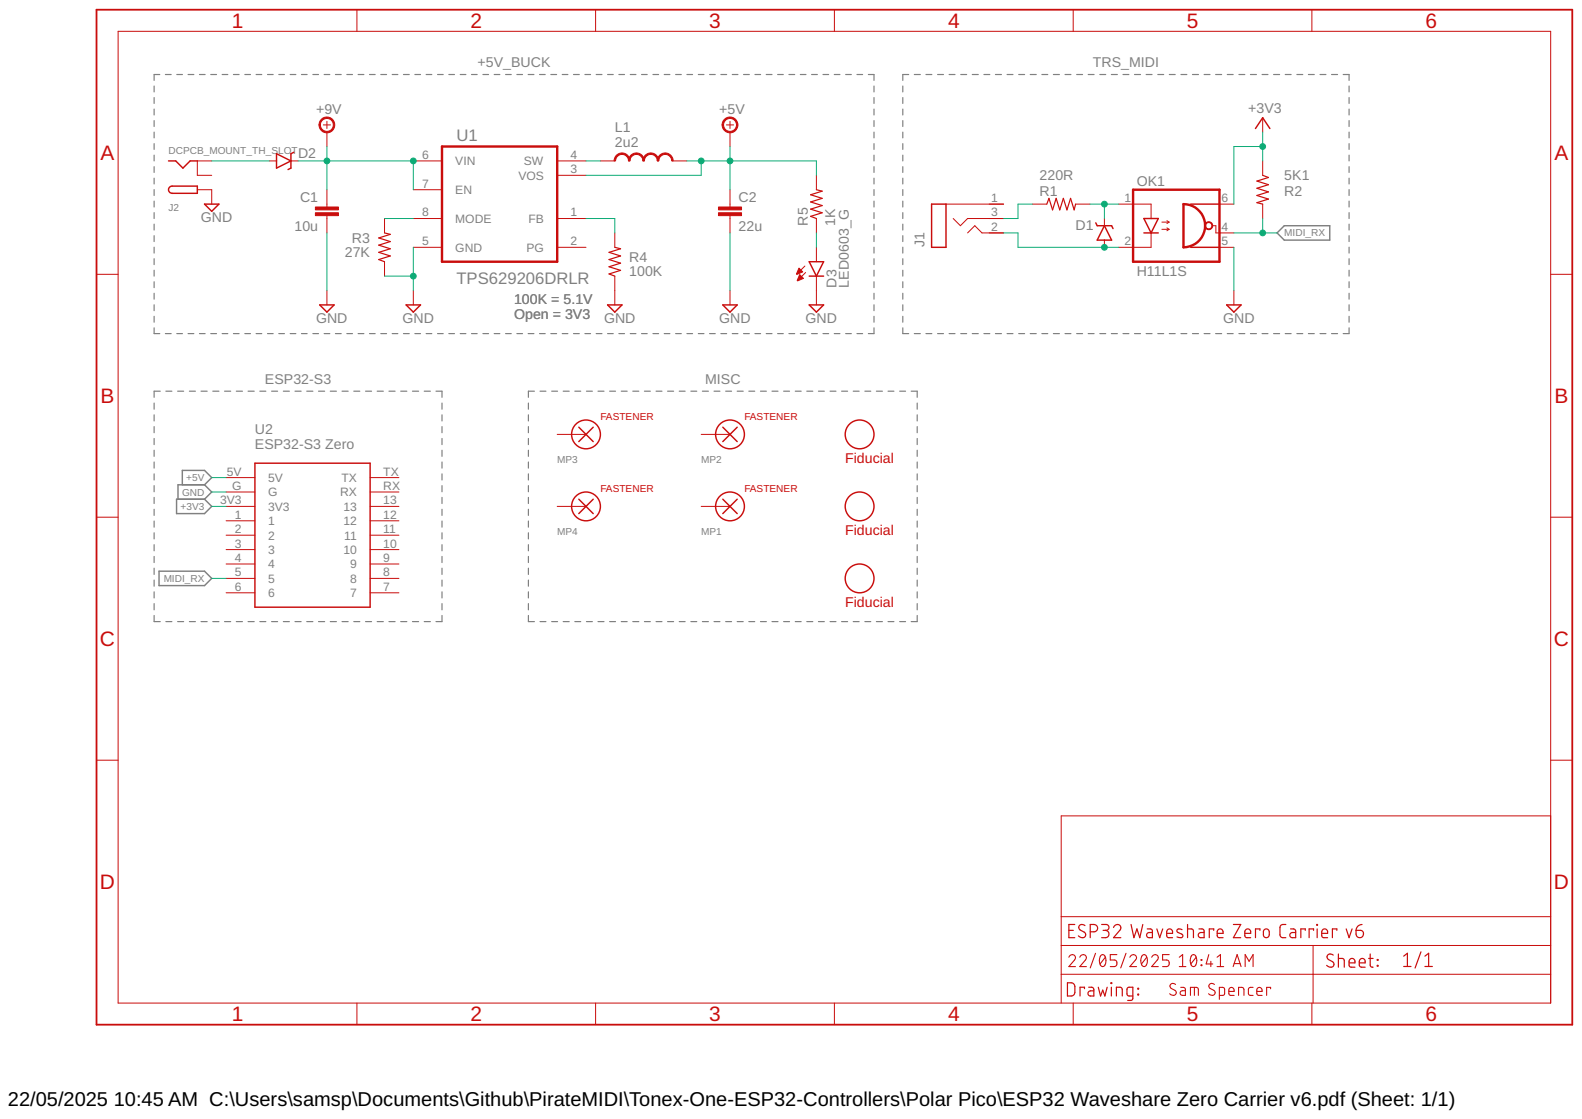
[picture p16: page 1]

22/05/2025 10:45 AM C:\Users\samsp\Documents\Github\PirateMIDI\Tonex-One-ESP32-Controllers\Polar Pico\ESP32 Waveshare Zero Carrier v6.pdf (Sheet: 1/1)

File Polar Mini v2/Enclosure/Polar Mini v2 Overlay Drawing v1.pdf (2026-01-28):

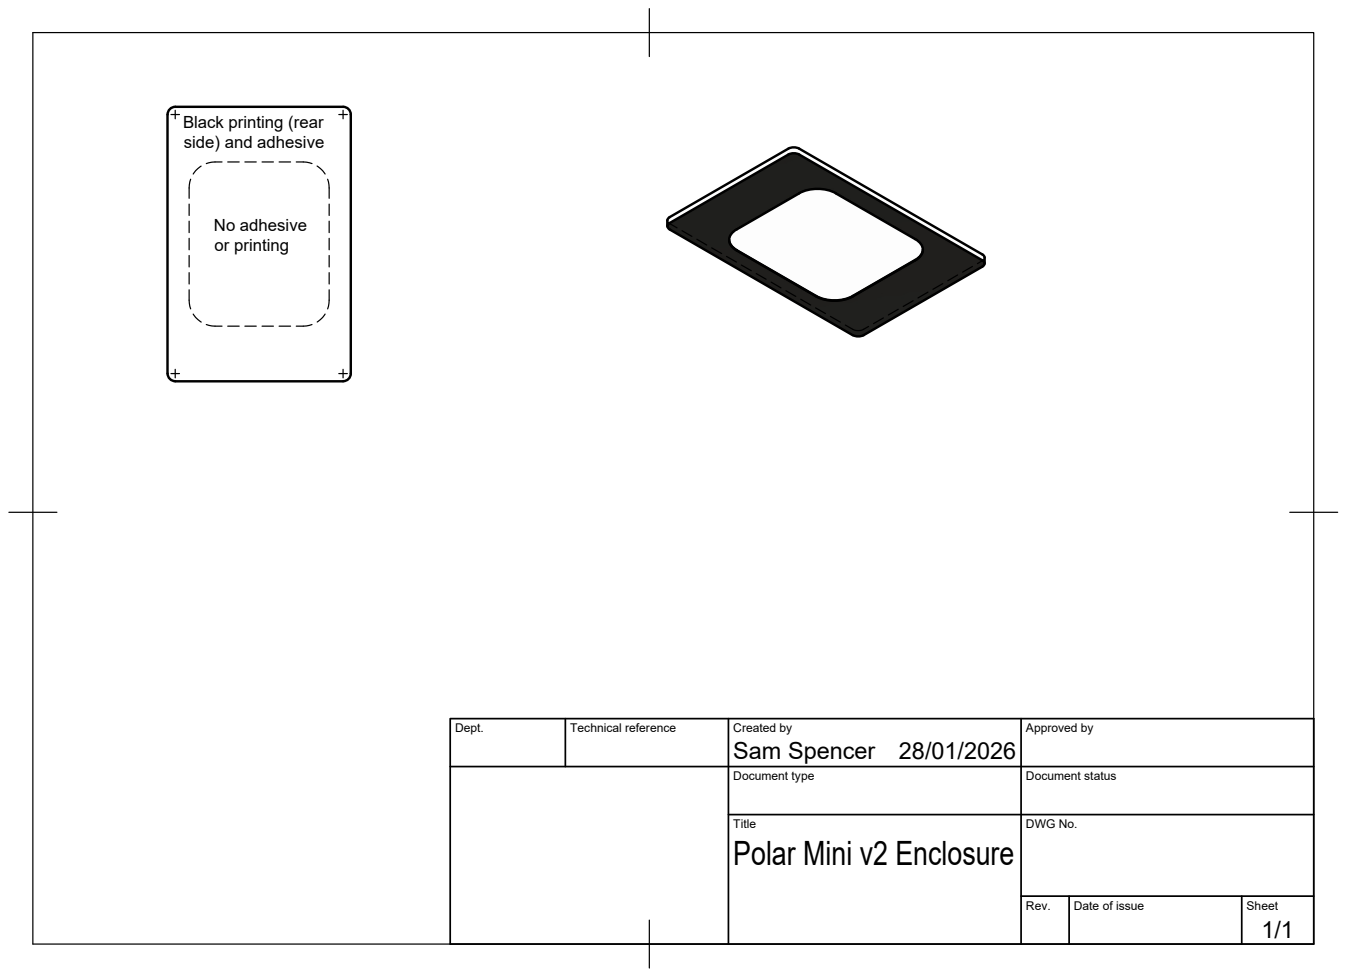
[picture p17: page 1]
No adhesive or printing

Black printing (rear
side) and adhesive

Dept. | Technical reference | Created by Sam Spencer 28/01/2026 | Approved by

Document type | Document status

Title Polar Mini v2 Enclosure | DWG No.

Rev. | Date of issue | Sheet 1/1

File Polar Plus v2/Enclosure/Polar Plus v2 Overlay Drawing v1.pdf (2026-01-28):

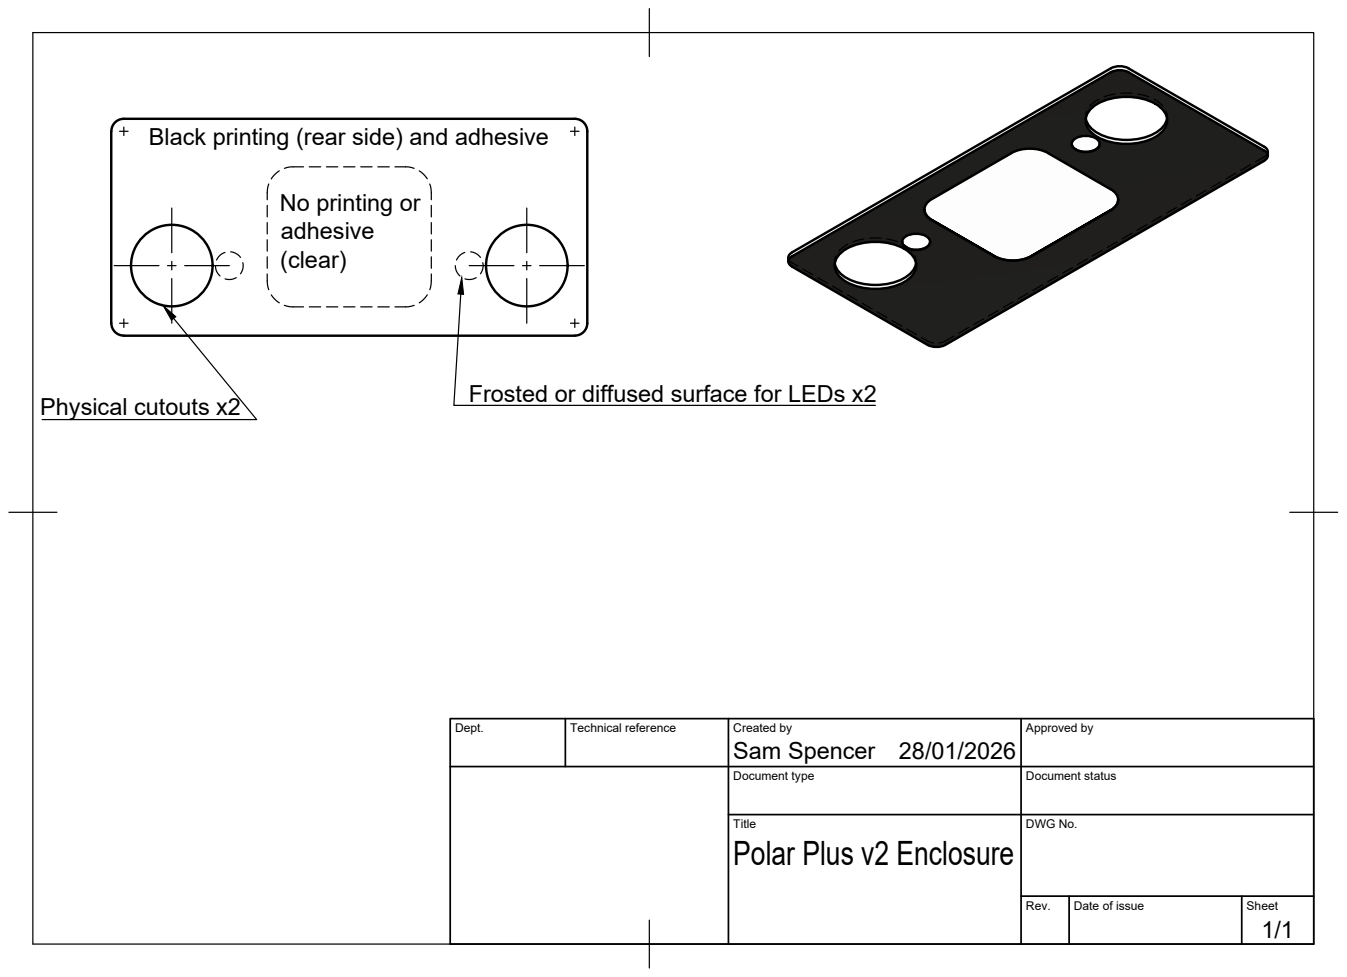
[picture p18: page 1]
Physical cutouts x2

Black printing (rear side) and adhesive

No printing or
adhesive
(clear)

Frosted or diffused surface for LEDs x2

Dept. | Technical reference | Created by Sam Spencer 28/01/2026 | Approved by

Document type | Document status

Title Polar Plus v2 Enclosure | DWG No.

Rev. | Date of issue | Sheet 1/1

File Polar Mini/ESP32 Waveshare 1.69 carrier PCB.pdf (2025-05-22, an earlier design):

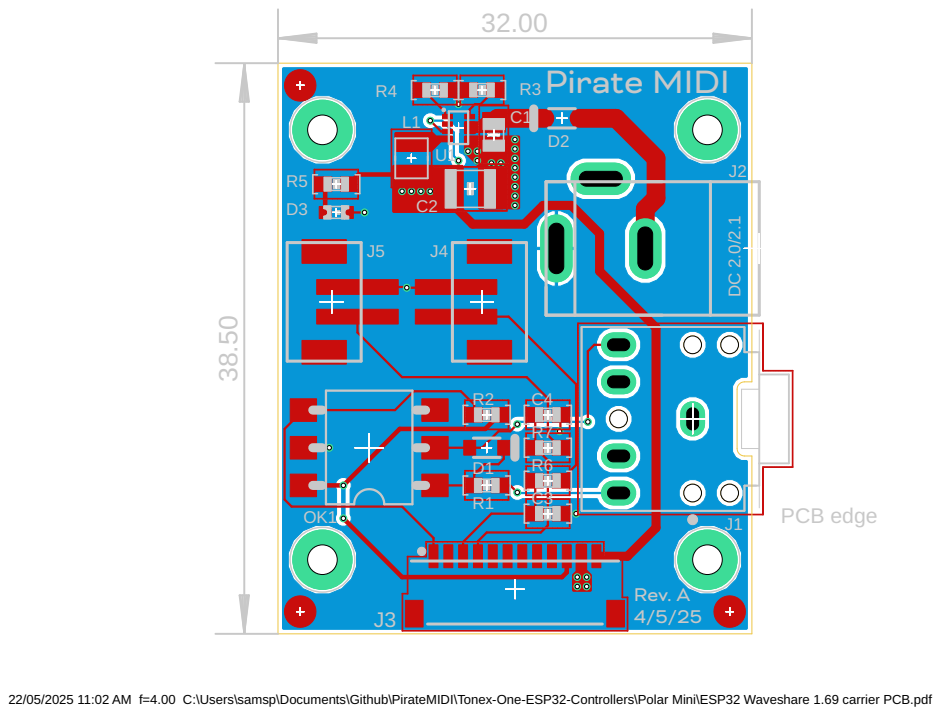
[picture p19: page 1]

22/05/2025 11:02 AM f=4.00 C:\Users\samsp\Documents\Github\PirateMIDI\Tonex-One-ESP32-Controllers\Polar Mini\ESP32 Waveshare 1.69 carrier PCB.pdf

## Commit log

2025-05-22 Initial Production File Upload
    [ESP32 Waveshare 1.69 Dual Enclosure v38.step, ESP32 Waveshare 1.69 Enclosure v77.step, ESP32 Waveshare Zero Enclosure v43.step]
2025-06-04 Updated with Overlay Drawings
    [ESP32 Waveshare Zero Enclosure v43.step, Polar Max Overlay.dxf, Polar Mini Overlay DXF.dxf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]
2025-07-01 Enclosure File Update
    Added Polar Max enclosure and updated Mini and Plus enclosure designs with better optimised mounting hole sizes.
    [ESP32 Waveshare 1.69 Dual Enclosure v38.step, ESP32 Waveshare 1.69 Enclosure v77.step, Polar Max Enclosure v105.step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]
2025-08-11 Added BOM and CPL files for PCBA
    [ESP32 Waveshare 1.69 Carrier v18_top_bom.csv, ESP32 Waveshare 1.69 Carrier v8.csv, ESP32 Waveshare Zero Carrier v6.csv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]
2026-01-28 v2 Manufacturing Files Updated
    [Polar Mini Enclosure v84.step, Polar Mini Enclosure v85.stl, Polar Mini v2 BOM.xlsx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]
2026-01-28 Added drawings and DXF files for the Mini and Plus v2 overlays
    [Polar Mini v2 Overlay Sketch.dxf, Polar Plus v2 Overlay Sketch.dxf]
2026-01-28 BOM Update
    Changes IR LED CLM values to 220R from 1K
    [Polar Plus v2.0.0 revA BOM.xlsx]
